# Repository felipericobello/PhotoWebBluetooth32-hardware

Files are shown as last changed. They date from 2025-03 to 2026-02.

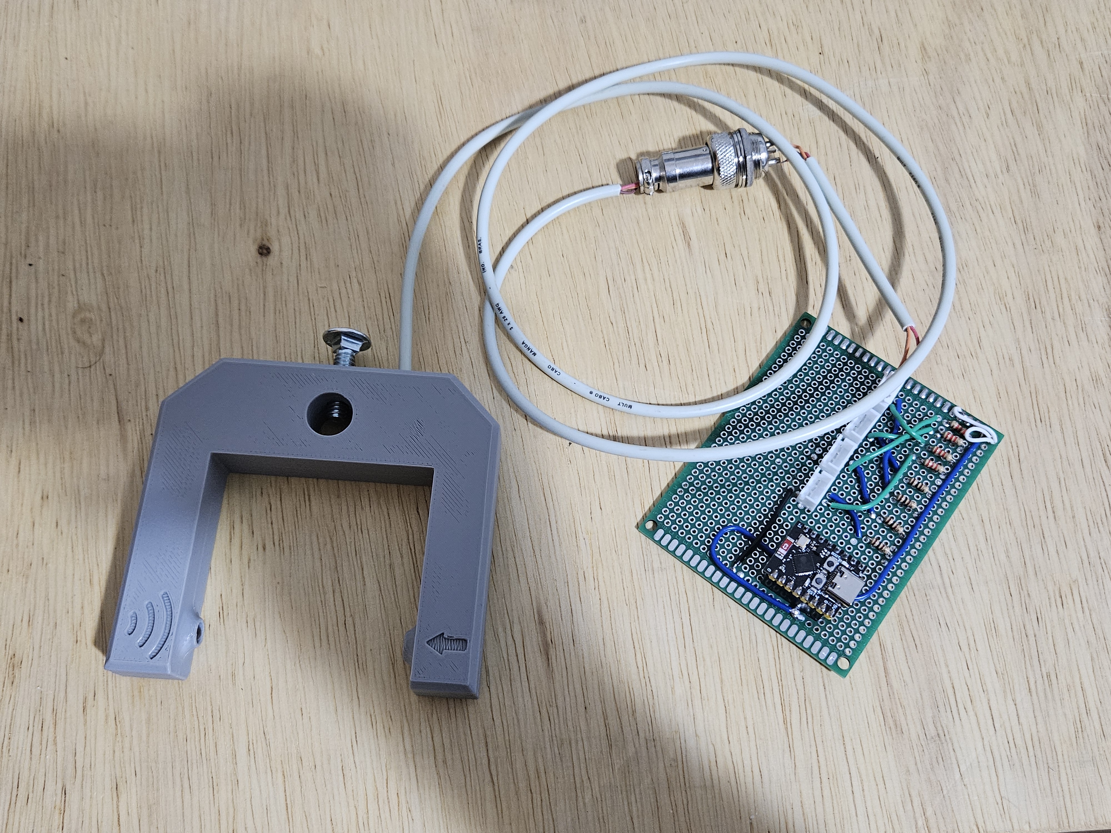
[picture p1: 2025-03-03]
images/20250224_165602.jpg

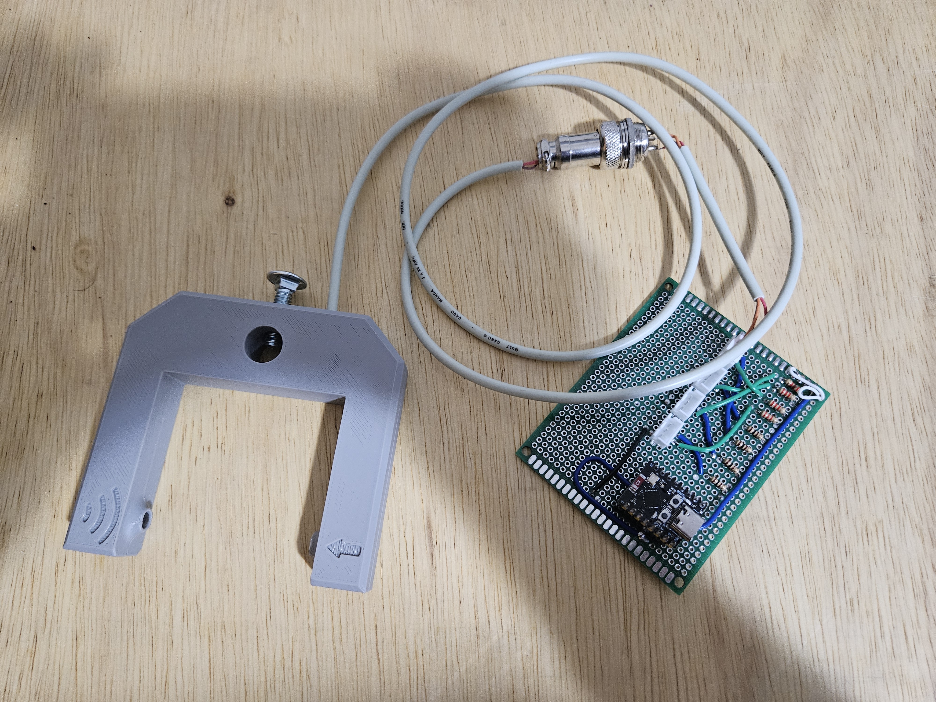
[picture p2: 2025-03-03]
images/image1.jpg

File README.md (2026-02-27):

# PhotoWebBluetooth (Hardware)

Este repositório contém todos os arquivos de hardware, esquemas eletrônicos e modelos 3D para a construção do sistema **PhotoWebBluetooth32 (PWB32)**.

O PWB32 é um sistema photogate de seis canais de baixo custo, desenvolvido para laboratórios de ensino de Física. Ele utiliza um microcontrolador ESP32 para detectar a passagem de objetos por sensores infravermelhos e transmite os dados via Bluetooth para uma interface web.

> **Nota:** Este hardware foi desenvolvido como parte do Trabalho de Conclusão de Curso de **Felipe Ricobello**, com colaboração técnica de **Aline de Almeida Soares** e **Fernando Rezende Apolinário** (CCA/UFSCar). Para o código-fonte do firmware e da interface web, acesse o repositório [PhotoWebBluetooth32](https://github.com/jocoteles/PhotoWebBluetooth32).

---

## 🛠 Conteúdo do Repositório

Este repositório está organizado nas seguintes pastas:

*   **`/PCB`**: Contém os esquemas do circuito, layout da PCB (se aplicável) e a lista de componentes (BOM) detalhada.
*   **`/STL`**: Inclui os arquivos STL e, possivelmente, os arquivos de projeto (ex: Fusion 360, OpenSCAD) para os cabeçotes dos sensores photogate e a caixa de acondicionamento do ESP32.
*   **`/DOCS`**: Apresenta diagramas de montagem, fotos do sistema finalizado e qualquer outra documentação relevante para a construção.

---

## 📋 Lista de Materiais (BOM - Bill of Materials)

Para montar uma unidade completa de 6 canais do PhotoWebBluetooth32, você precisará dos seguintes componentes:

### Eletrônica Principal
*   1x **ESP32 DevKit V1** (com 30 pinos, ou modelo compatível).
*   6x **Pares Infravermelhos** (compostos por 1x LED IR emissor e 1x Fototransistor receptor cada).
*   6x **Resistores para os LEDs IR** (valor típico: 150Ω a 220Ω, dimensionado conforme a corrente desejada e tensão de alimentação do LED).
*   6x **Resistores de pull-up para os fototransistores** (valor típico: 10kΩ).
*   **Cabos de conexão:** Fios para ligar os sensores ao ESP32 (recomenda-se cabos blindados ou do tipo flat para os sensores para maior organização e menos ruído).
*   **Conectores (opcional):** Conectores de 3 pinos (ex: JST, GX16) para os sensores para facilitar a modularidade e substituição.
*   **Protoboard ou PCB:** Para a montagem do circuito de condicionamento de sinal e conexão dos sensores.

### Estrutura (Impressão 3D)
*   6x **Corpos de cabeçotes de sensores** (design em "U" disponível em `/modelagem-3d`, para garantir o alinhamento do feixe IR).
*   1x **Caixa de controle** (disponível em `/modelagem-33`, para abrigar o ESP32 e as conexões principais).
*   **Parafusos e porcas** para fixação (detalhes no manual de montagem).

---

## 🔌 Pinagem e Circuito

O firmware padrão do PhotoWebBluetooth32 espera que os sensores photogate sejam conectados aos seguintes pinos analógicos do ESP32:

| Canal | Pino ESP32 (ADC) | Função |
| :--- | :--- | :--- | :--- |
| Canal 1 | GPIO 34 | Sensor Photogate 1 |
| Canal 2 | GPIO 35 | Sensor Photogate 2 |
| Canal 3 | GPIO 32 | Sensor Photogate 3 |
| Canal 4 | GPIO 33 | Sensor Photogate 4 | 
| Canal 5 | GPIO 25 | Sensor Photogate 5 | 
| Canal 6 | GPIO 26 | Sensor Photogate 6 |

**Diagrama Básico do Sensor Photogate:**

Cada sensor photogate consiste em um LED infravermelho e um fototransistor. O fototransistor é conectado em uma configuração de divisor de tensão, onde sua resistência varia drasticamente com a incidência de luz IR.

Quando um objeto passa e bloqueia o feixe IR, o fototransistor para de conduzir, e a tensão no pino ADC sobe (ou desce, dependendo da configuração). O firmware detecta essa mudança para registrar o evento.

Para o esquema detalhado e layout da PCB, consulte a pasta `/PCB`.

---

## 📐 Montagem Física

1.  **Impressão 3D:** Imprima todas as peças estruturais (`cabeçotes`, `caixa_controle`) utilizando os arquivos STL fornecidos em `/STL`. Recomenda-se PETG ou ABS para durabilidade.
2.  **Montagem da Eletrônica:**
    *   Soldar os resistores e o fototransistor para cada cabeçote de sensor.
    *   Montar o circuito de condicionamento de sinal (se houver) em uma protoboard ou PCB.
    *   Conectar os fios dos 6 sensores aos pinos do ESP32 conforme a tabela de pinagem acima.
    *   Garantir boas conexões de alimentação (3.3V e GND) para o ESP32 e os sensores.
3.  **Acondicionamento:**
    *   Encaixe o ESP32 dentro da caixa de controle impressa.
    *   Passe os cabos dos sensores pelas aberturas da caixa e conecte-os de forma organizada.
    *   Certifique-se de que a antena Wi-Fi/Bluetooth do ESP32 não esteja obstruída por componentes metálicos para garantir a melhor conectividade.
4.  **Montagem dos Cabeçotes:** Insira o LED IR e o fototransistor em seus respectivos orifícios nos cabeçotes impressos. O design em "U" deve facilitar o alinhamento.
5.  **Verificação:** Antes de fechar a caixa, faça uma verificação visual de todas as conexões e soldas.

Para um guia de montagem passo a passo com fotos, consulte a pasta `/documentacao`.

---

## 🚀 Como Integrar com o Software

Após a montagem do hardware:

1.  **Grave o Firmware:** Siga as instruções no repositório [PhotoWebBluetooth32](https://github.com/jocoteles/PhotoWebBluetooth32) para compilar e gravar o firmware `PWB32Server.ino` no seu ESP32.
2.  **Teste com a PWA:** Acesse a Progressive Web App (PWA) em [https://jocoteles.github.io/PhotoWebBluetooth32/](https://jocoteles.github.io/PhotoWebBluetooth32/) com um navegador compatível (Chrome, Edge, Opera em desktop ou Android).
3.  **Calibração:** Utilize a aba "Config" da PWA para ajustar os níveis de trigger de cada canal do photogate conforme as condições de luz do ambiente e a opacidade dos objetos a serem detectados.

---

## 📄 Licença

Este projeto de hardware é liberado sob uma licença de hardware aberto (ex: CERN OHL-P ou Creative Commons Attribution-ShareAlike 4.0 International). Sinta-se à vontade para modificar e melhorar os designs, desde que cite os autores originais.

---
*Desenvolvido para os Laboratórios de Ensino de Física do [CCA/UFSCar](https://www.fisicaararas.ufscar.br/pt-br).*

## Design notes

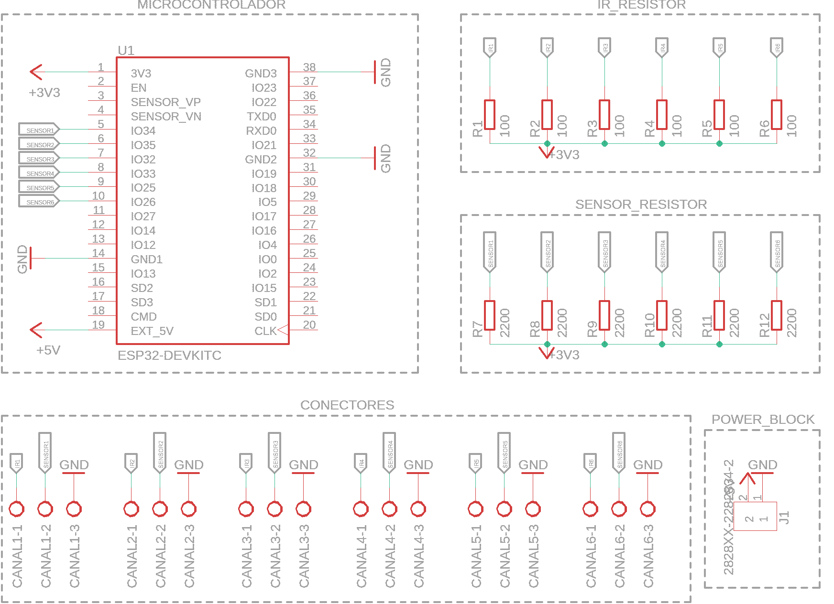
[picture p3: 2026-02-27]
PCB/images/PCB_schm.png

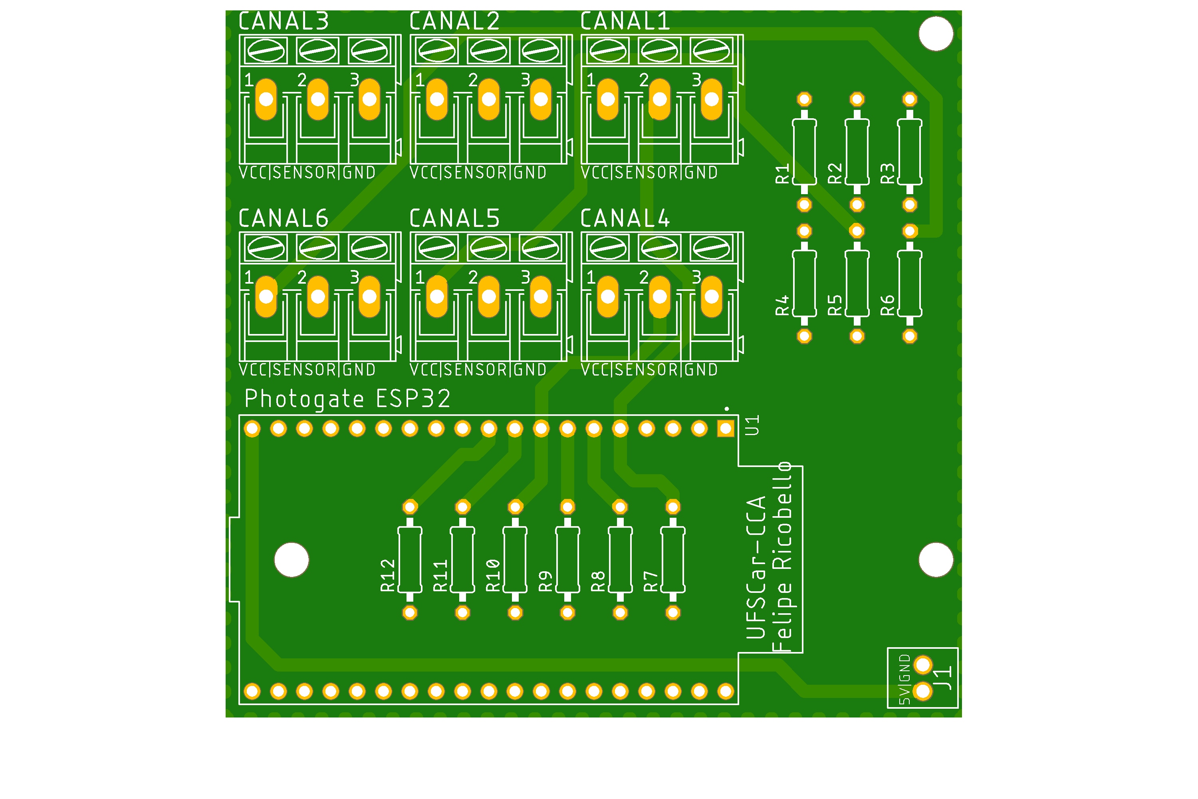
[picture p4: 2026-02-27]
PCB/images/PCB_topside.png

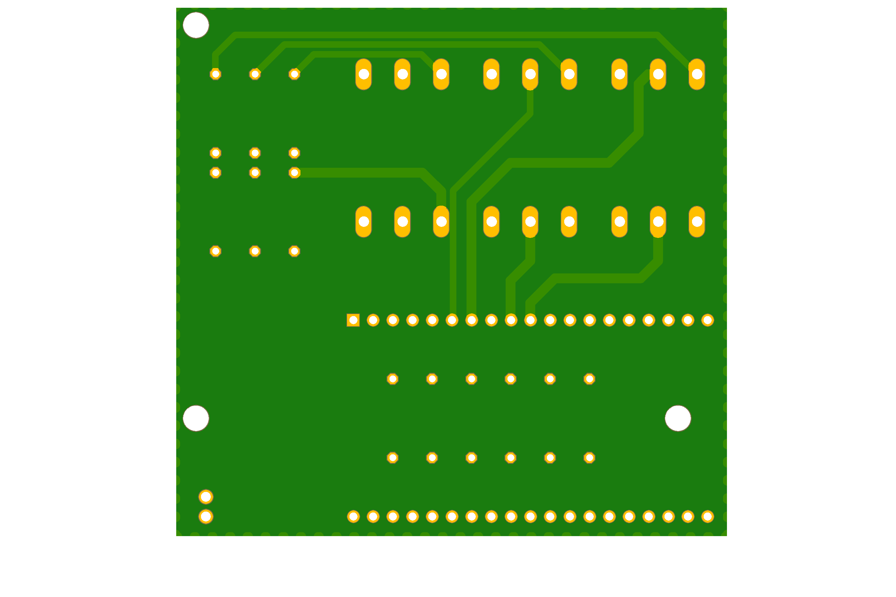
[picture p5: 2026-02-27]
PCB/images/PCB_bottomside.png

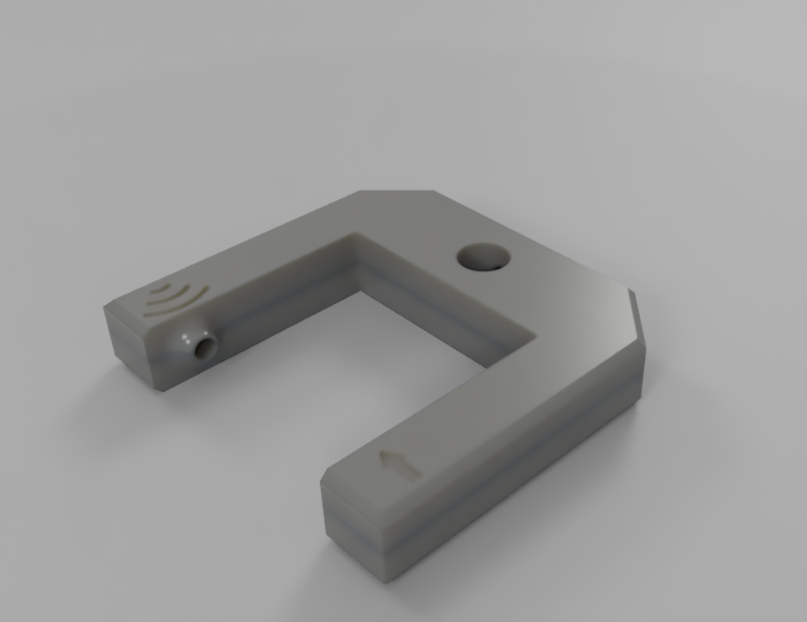
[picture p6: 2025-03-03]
images/Photogate_render1.png

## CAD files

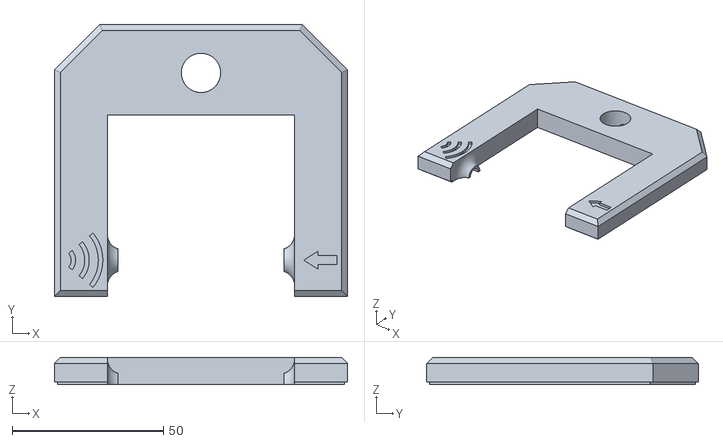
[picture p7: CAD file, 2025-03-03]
STL/fdm/Photogate_Top.stl
97.0 x 90.0 x 9.00

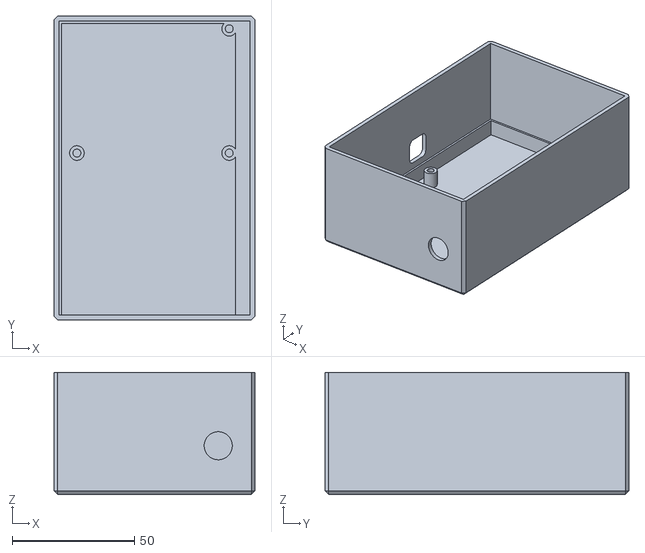
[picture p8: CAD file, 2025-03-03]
STL/fdm/shield_design/Shield_Bottom_V1.stl
82.1 x 124.2 x 50.0

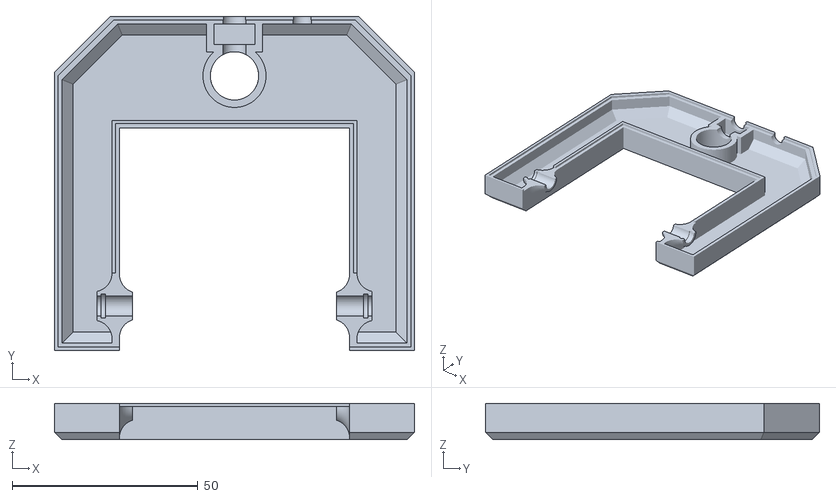
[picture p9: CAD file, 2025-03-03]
STL/fdm/Photogate_Bottom.stl
97.0 x 90.0 x 9.80

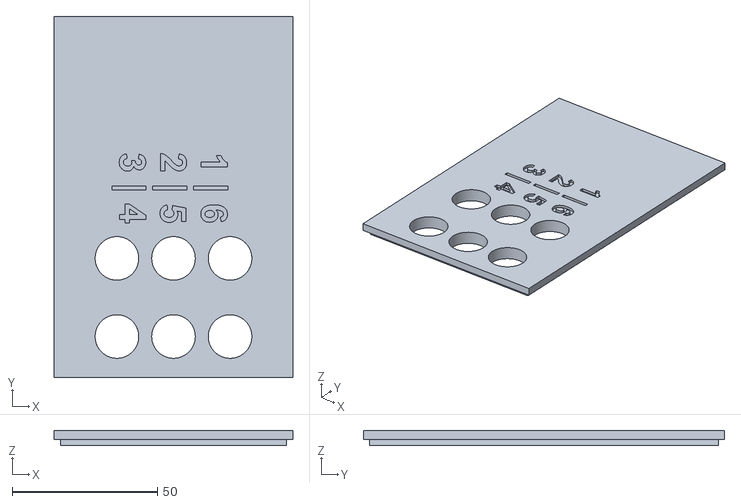
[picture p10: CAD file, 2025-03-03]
STL/fdm/shield_design/Shield_Top_V1.stl
82.1 x 124.2 x 5.00

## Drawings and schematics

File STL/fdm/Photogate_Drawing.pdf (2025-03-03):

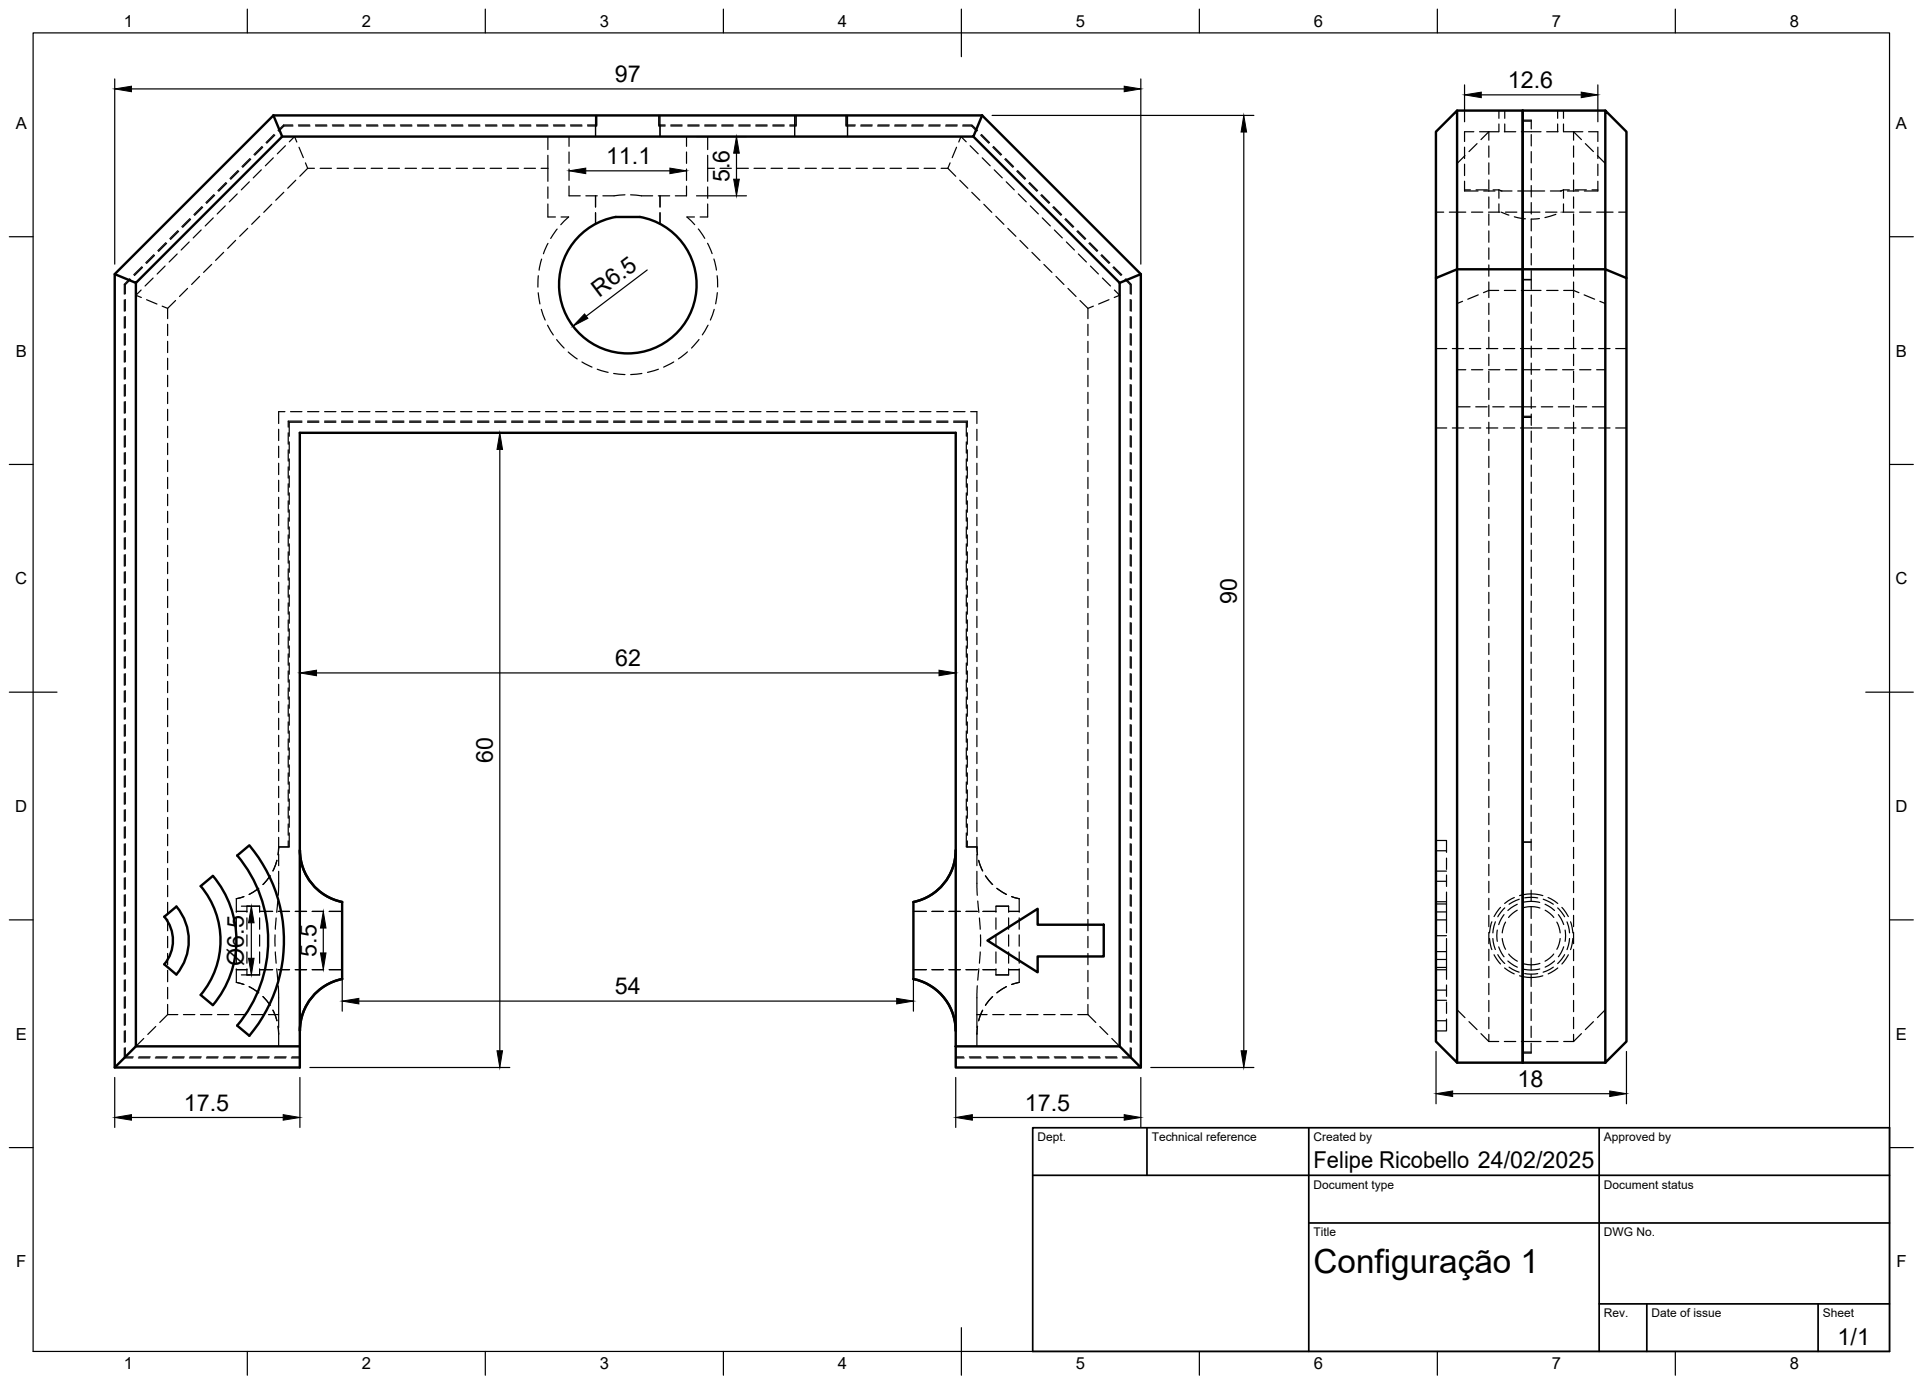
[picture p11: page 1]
Title; DWG No.; Rev.; Date of issue; Sheet; Configuração 1

Dept. | Technical reference | Created by Felipe Ricobello 24/02/2025 | Approved by

Document type | Document status

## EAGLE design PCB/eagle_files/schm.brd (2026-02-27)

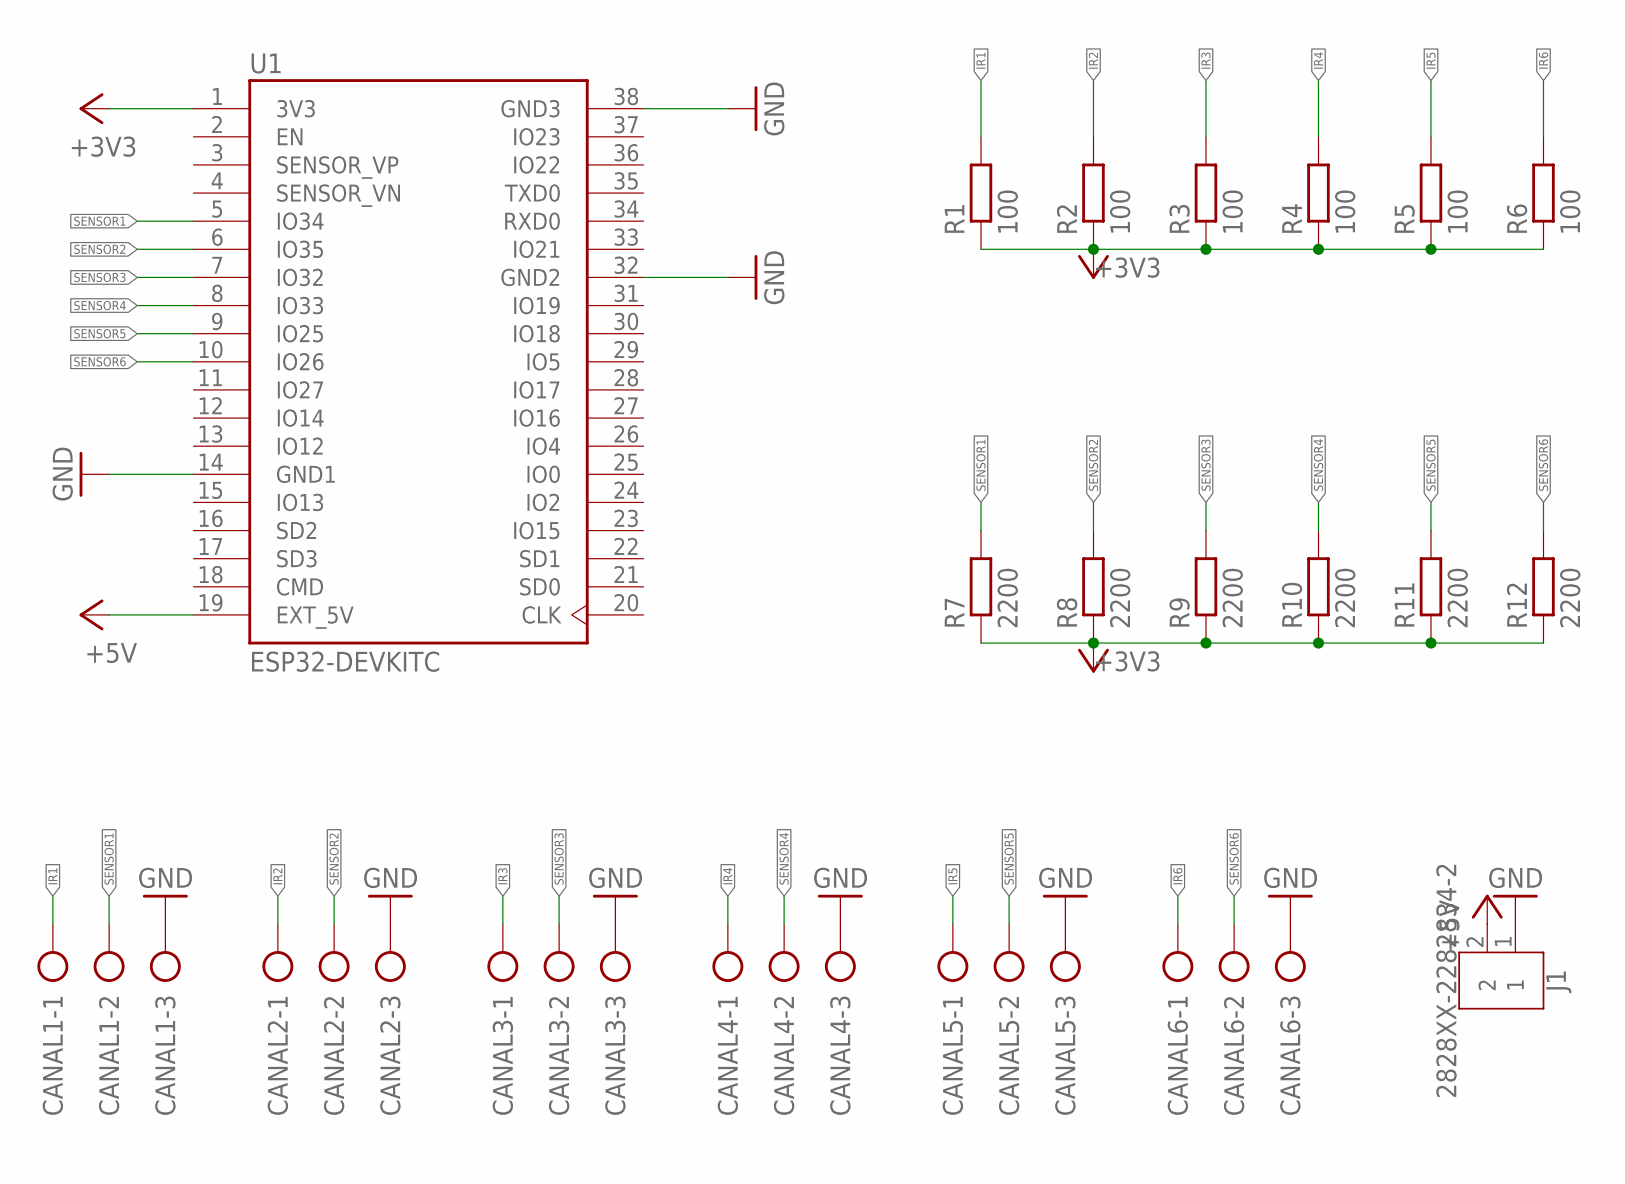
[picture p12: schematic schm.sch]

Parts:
CANAL1, CANAL2, CANAL3, CANAL4, CANAL5, CANAL6: AK300/3
J1: 2828XX-2282834-2; TERMBLK_254-2N
R1, R2, R3, R4, R5, R6: 100; 0207/10
R7, R8, R9, R10, R11, R12: 2200; 0207/10
U1: ESP32-DEVKITC; MODULE_ESP32-DEVKITC

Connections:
+3V3: R1.1, R2.1, R3.1, R4.1, R5.1, R6.1, R7.1, R8.1, R9.1, R10.1, R11.1, R12.1, U1.1 (3V3)
+5V: J1.2, U1.19 (EXT_5V)
GND: CANAL1.3, CANAL2.3, CANAL3.3, CANAL4.3, CANAL5.3, CANAL6.3, J1.1, U1.14 (GND1), U1.32 (GND2), U1.38 (GND3)
IR1: CANAL1.1, R1.2
IR2: CANAL2.1, R2.2
IR3: CANAL3.1, R3.2
IR4: CANAL4.1, R4.2
IR5: CANAL5.1, R5.2
IR6: CANAL6.1, R6.2
SENSOR1: CANAL1.2, R7.2, U1.5 (IO34)
SENSOR2: CANAL2.2, R8.2, U1.6 (IO35)
SENSOR3: CANAL3.2, R9.2, U1.7 (IO32)
SENSOR4: CANAL4.2, R10.2, U1.8 (IO33)
SENSOR5: CANAL5.2, R11.2, U1.9 (IO25)
SENSOR6: CANAL6.2, R12.2, U1.10 (IO26)

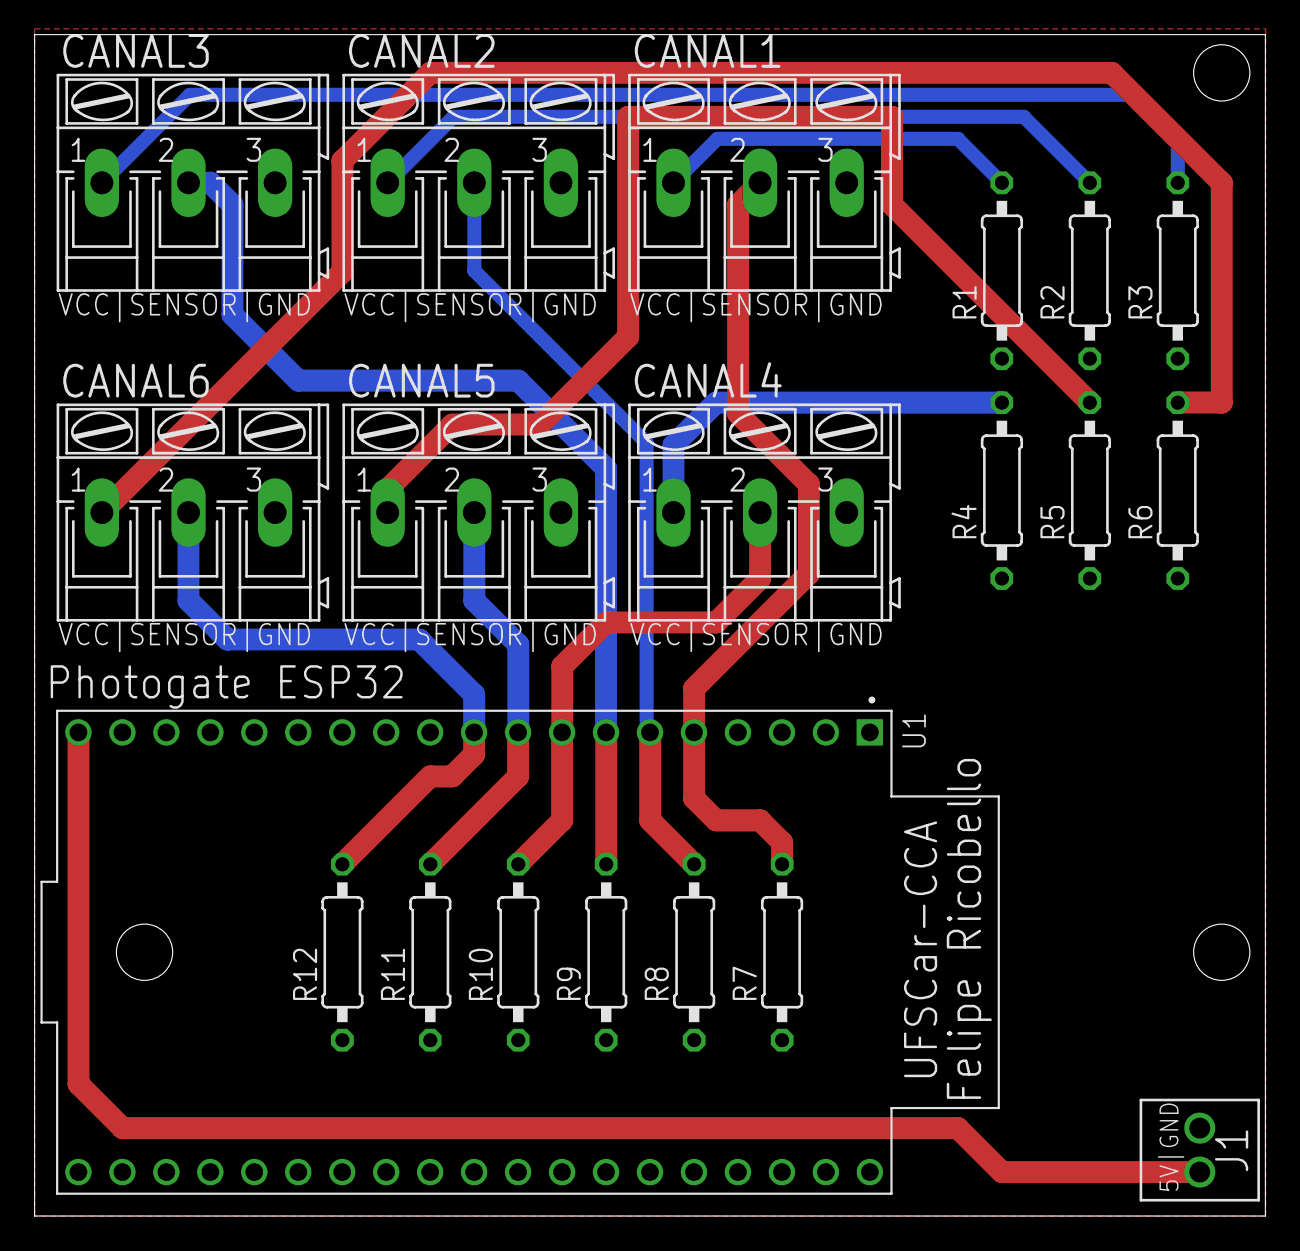
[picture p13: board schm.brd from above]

Board: 2 copper layers, 71.1 x 68.2 mm, 20 parts (0 on the bottom side), 15 nets.

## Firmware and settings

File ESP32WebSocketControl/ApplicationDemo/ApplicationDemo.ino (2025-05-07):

/**
 * @file ApplicationDemo.ino
 * @brief Example application demonstrating the use of ESP32WebSocketControl library.
 *        Implements both Get/Set variable control via JSON and high-frequency 
 *        binary data streaming of 6 analog inputs.
 */

// Include our custom WebSocket communication library
#include "ESP32WebSocketControl.h" 

// --- WiFi Access Point Configuration ---
const char *WIFI_SSID = "ESP32_Control_AP";      // Network name for clients to connect to
const char *WIFI_PASSWORD = "password123"; // Network password (min 8 chars)

// --- Get/Set Variable Configuration (JSON Communication) ---

// Define the variables that can be read/written via JSON commands
// (Uses the VariableConfig struct from ESP32WebSocketControl.h)
VariableConfig configurableVariables[] = {
  // Name             Type        Int Val  Float Val  String Val   Min     Max     Limits?
  {"led_intensity",   TYPE_INT,   128,     0.0f,      "",          0.0,    255.0,  true},
  {"update_interval", TYPE_INT,   500,     0.0f,      "",          50.0,   5000.0, true},
  {"motor_enable",    TYPE_INT,   0,       0.0f,      "",          0.0,    1.0,    true}, // Example: 0=off, 1=on
  {"device_label",    TYPE_STRING,0,       0.0f,      "ESP32-01",  0.0,    0.0,    false} 
};
// Automatically calculate the number of configurable variables
const int numConfigurableVariables = sizeof(configurableVariables) / sizeof(configurableVariables[0]);


// --- Real Time Reading (Streaming) Configuration ---

// Constants for data acquisition and buffering
const int SAMPLES_PER_CHUNK = 25;       // How many readings to buffer before sending (N)
const int SAMPLE_INTERVAL_US = 250;     // Time between samples in microseconds (adjust for desired rate)

// Define the 6 Analog Input pins to be read
// Note: Ensure these pins are suitable for ADC use on your specific ESP32 board.
//       ADC1 pins (GPIO 32-39) are generally safe. Avoid ADC2 pins if using WiFi.
const int ANALOG_PIN_1 = 32; 
const int ANALOG_PIN_2 = 33;
const int ANALOG_PIN_3 = 34;
const int ANALOG_PIN_4 = 35;
const int ANALOG_PIN_5 = 36; // Often VP
const int ANALOG_PIN_6 = 39; // Often VN

// Structure for a single packet of sensor data (matches client-side expectation)
// Use pragma pack to ensure no padding bytes are added by the compiler.
#pragma pack(push, 1) 
struct SensorDataPacket {
  uint16_t reading1;    // Reading from ANALOG_PIN_1
  uint16_t reading2;    // Reading from ANALOG_PIN_2
  uint16_t reading3;    // Reading from ANALOG_PIN_3
  uint16_t reading4;    // Reading from ANALOG_PIN_4
  uint16_t reading5;    // Reading from ANALOG_PIN_5
  uint16_t reading6;    // Reading from ANALOG_PIN_6
  uint32_t time_ms;     // Timestamp (milliseconds) relative to stream start
};                      // Total size = 6 * 2 + 4 = 16 bytes
#pragma pack(pop) 

// Calculate sizes based on the structure and chunk configuration
const int PACKET_SIZE_BYTES = sizeof(SensorDataPacket);       // Size of one packet (16 bytes)
const int CHUNK_BUFFER_SIZE_BYTES = SAMPLES_PER_CHUNK * PACKET_SIZE_BYTES; // Total size of the send buffer

// Buffer to hold sensor data before sending
SensorDataPacket sensorDataBuffer[SAMPLES_PER_CHUNK];
// Index pointing to the next available slot in the buffer
int currentBufferIndex = 0;

// --- Application State Variables ---
bool isAppStreaming = false;      // Flag controlled by callbacks, enables/disables streaming logic in loop()
uint32_t streamStartTimeMs = 0;   // Records the time when streaming started (using millis())


// --- Stream Control Callback Functions (Required by the Library) ---

/**
 * @brief This function is called by the ESP32WebSocketControl library 
 *        when a "start_stream" command is received from a client.
 *        It sets up the application state to begin data acquisition.
 */
void application_onStreamStart() {
  Serial.println("Application Callback: START STREAM requested.");
  currentBufferIndex = 0;          // Reset buffer index
  streamStartTimeMs = millis();    // Record the start time for relative timestamps
  isAppStreaming = true;           // Set the flag to enable streaming logic in loop()
  // Optional: Could add actions like enabling sensor power here.
}

/**
 * @brief This function is called by the ESP32WebSocketControl library
 *        when a "stop_stream" command is received or the last client disconnects.
 *        It sets the application state to stop data acquisition.
 */
void application_onStreamStop() {
  Serial.println("Application Callback: STOP STREAM requested.");
  isAppStreaming = false;          // Clear the flag to disable streaming logic in loop()
  // Optional: Could add actions like disabling sensor power here.
}


// --- Arduino Setup Function ---

/**
 * @brief Initializes Serial communication, configures pins, and starts the 
 *        WiFi/WebSocket server using the ESP32WebSocketControl library.
 */
void setup() {
  // Start Serial communication for debugging and status messages
  Serial.begin(115200);
  delay(500); // Pequena pausa para garantir que o Serial esteja pronto
  Serial.println("\n\n--- [APP_DEMO] Setup: START ---"); // << NOVO LOG

  // Configure the specified analog input pins
  Serial.println("[APP_DEMO] Setup: Configuring analog pins..."); // << NOVO LOG
  pinMode(ANALOG_PIN_1, INPUT); 
  pinMode(ANALOG_PIN_2, INPUT); 
  pinMode(ANALOG_PIN_3, INPUT);
  pinMode(ANALOG_PIN_4, INPUT); 
  pinMode(ANALOG_PIN_5, INPUT); 
  pinMode(ANALOG_PIN_6, INPUT);
  Serial.println("[APP_DEMO] Setup: Analog pins configured."); // << NOVO LOG
  
  Serial.println("[APP_DEMO] Setup: Calling initWiFiWebSocketServer..."); // << NOVO LOG
  initWiFiWebSocketServer(WIFI_SSID, WIFI_PASSWORD, configurableVariables, numConfigurableVariables); 
  Serial.println("[APP_DEMO] Setup: initWiFiWebSocketServer CALL RETURNED."); // << NOVO LOG

  Serial.println("[APP_DEMO] Setup: Calling setStreamCallbacks..."); // << NOVO LOG
  setStreamCallbacks(application_onStreamStart, application_onStreamStop);
  Serial.println("[APP_DEMO] Setup: setStreamCallbacks CALL RETURNED."); // << NOVO LOG

  Serial.printf("[APP_DEMO] Streaming Config: %d samples/chunk, %d us/sample interval.\n", 
                SAMPLES_PER_CHUNK, SAMPLE_INTERVAL_US);
  Serial.printf("[APP_DEMO] Data Packet Size: %d bytes. Chunk Buffer Size: %d bytes.\n", 
                PACKET_SIZE_BYTES, CHUNK_BUFFER_SIZE_BYTES);

  Serial.println("--- [APP_DEMO] Setup: COMPLETE ---"); // << NOVO LOG
  Serial.println("[APP_DEMO] Waiting for client connections...");
}


// --- Arduino Loop Function ---

/**
 * @brief Main application loop. Handles the real-time data acquisition and buffering
 *        when streaming is active. The WebSocket communication itself is handled 
 *        asynchronously by the ESP32WebSocketControl library in the background.
 */
void loop() {

  // Check if the application should be actively streaming data
  if (isAppStreaming) {
    
    // --- 1. Read Analog Sensors ---
    // Read the voltage level from each configured analog pin.
    // The raw reading is typically 0-4095 for 12-bit ADC.
    uint16_t val1 = analogRead(ANALOG_PIN_1);
    uint16_t val2 = analogRead(ANALOG_PIN_2);
    uint16_t val3 = analogRead(ANALOG_PIN_3);
    uint16_t val4 = analogRead(ANALOG_PIN_4);
    uint16_t val5 = analogRead(ANALOG_PIN_5);
    uint16_t val6 = analogRead(ANALOG_PIN_6);

    // --- 2. Get Timestamp ---
    // Calculate the time elapsed since the stream started.
    uint32_t currentTimeMs = millis() - streamStartTimeMs; 

    // --- 3. Fill Buffer ---
    // Store the readings and timestamp into the current slot of the data buffer.
    sensorDataBuffer[currentBufferIndex].reading1 = val1;
    sensorDataBuffer[currentBufferIndex].reading2 = val2;
    sensorDataBuffer[currentBufferIndex].reading3 = val3;
    sensorDataBuffer[currentBufferIndex].reading4 = val4;
    sensorDataBuffer[currentBufferIndex].reading5 = val5;
    sensorDataBuffer[currentBufferIndex].reading6 = val6;
    sensorDataBuffer[currentBufferIndex].time_ms = currentTimeMs;

    // Move to the next position in the buffer.
    currentBufferIndex++; 

    // --- 4. Check if Buffer is Full and Send ---
    // If the buffer has reached the configured chunk size...
    if (currentBufferIndex >= SAMPLES_PER_CHUNK) {
      // ...send the entire buffer as a single binary message to all connected clients
      // using the library function.
      broadcastBinaryData((uint8_t*)sensorDataBuffer, CHUNK_BUFFER_SIZE_BYTES);
      
      // Reset the buffer index to start filling the next chunk.
      currentBufferIndex = 0; 
    }

    // --- 5. Wait for Sample Interval ---
    // Pause execution for the configured time before taking the next sample.
    // Using delayMicroseconds allows for higher sampling rates than delay().
    delayMicroseconds(SAMPLE_INTERVAL_US); 

  } else {
    // --- Idle State (Not Streaming) ---
    // If streaming is not active, the application can perform other tasks
    // or simply wait to conserve power/CPU.
    
    // Example: Read a configurable variable and print it periodically
    static unsigned long lastPrintTime = 0;
    unsigned long interval = configurableVariables[1].intValue; // Use 'update_interval'
    if (millis() - lastPrintTime > interval) {
       lastPrintTime = millis();
       // Serial.printf("Idle: LED Intensity = %d\n", configurableVariables[0].intValue);
    }

    // A short delay when idle prevents the loop from running at maximum speed unnecessarily.
    delay(50); 
  }

  // Optional: Periodically clean up disconnected WebSocket clients.
  // Often not needed in the loop as the library handles much of it.
  // cleanupWebSocketClients();

} // End main loop()

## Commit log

2025-02-24 Rise and fall timestamps working!!!
    [pcb1-proto-supp.stl, suporte_photogate.stl]
2025-03-03 OLED implementated
    [PhotogateV2_Bottom.stl, PhotogateV2_Linhas.stl, PhotogateV2_Seta.stl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]
2025-05-05 ESP32WebSocketControl created
2025-05-09 ESP32WebSocketControl strongly modularized
2025-05-09 Mudancas pcb
    [schematic.brd, schematic.sch]
2026-02-27 Atualizacao Hardware
    [pcb1-proto-supp.stl, schm.brd, schm.sch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]
